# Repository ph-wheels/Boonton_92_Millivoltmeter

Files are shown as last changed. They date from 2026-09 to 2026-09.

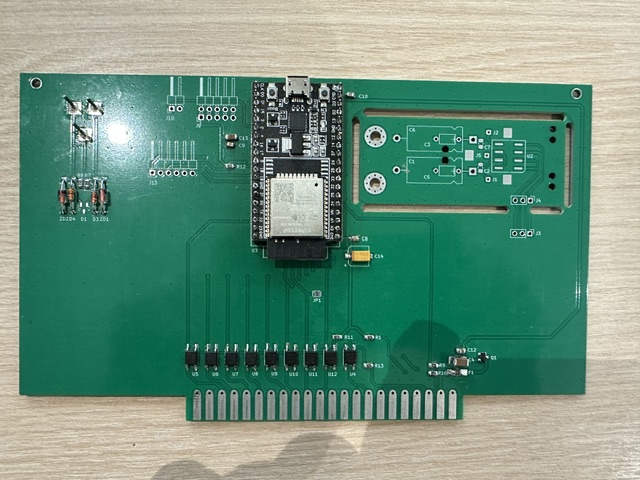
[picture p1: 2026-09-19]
IMG_92BD_V27.JPG

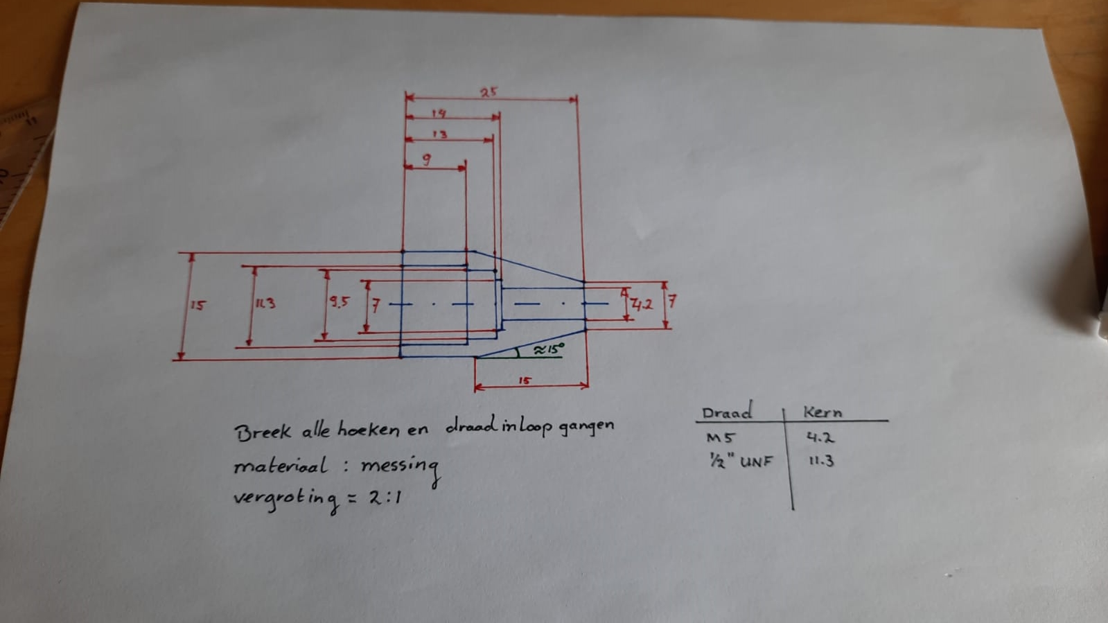
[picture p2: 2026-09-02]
IMG_92BD_Probe_Head.jpg

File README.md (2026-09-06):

# How to Fix & Add an Auto-Range Option to Your Boonton 92 Series RF Millivolt Meter

## Background

Some years ago I came across a 92BD RF Millivolt Meter in reasonably good condition. After a while it started showing problems that indicated the chopper tube was nearing end of life. Since these tubes are no longer available, the meter was effectively unusable.

I found a possible solution: replace the entire front end with a couple of low-drift op-amps and their associated gain-selection circuitry. This design was created by Jacques Audet, built on perfboard with a connector suitable for the 92 series backplane. I started laying out a PCB for it, but never actually built one.

## The SSR Idea

As part of another project, I became interested in solid-state relays (SSRs) that use MOSFETs, with the drive circuit electrically isolated from the signal. These devices can be driven with just a few mA, the MOSFET turns on within a microsecond, and it has very low Rds(on) resistance.

That's when the idea came up: replace the chopper tube with two SSRs (both housed in a single physical package). My original MCU-based auto-ranging extension board was redesigned into a new PCB that would handle both:

- The (already working) auto-ranging function, inital version ran on Arduino PCB
- The drive circuit for the SSRs

## Signal Path & Wiring

Since signal levels are quite low, and noise had to be minimized, I built an additional small PCB that mounts directly behind the signal input connector, with short leads to the SSR PCB and a single lead to the original analog input on the backplane.

A set of twisted control wires runs from the SSR PCB to a few free pins on backplane connector **J103**, which was originally intended for the auto-ranging board. On this connector, one additional connection is also needed: a jumper wire supplying +5V DC to the auto-ranging connector J103.

## System Overview

The current design consists of two parts, both controlled by the MCU:

1. **Auto-ranging circuit**
2. **SSR control circuit**

For the MCU I used an **ESP32** (with both Bluetooth and WiFi disabled). The choice was based on prior projects and the large number of available I/O pins.

### Handling Negative Control Voltages

The 92 series meter uses negative control voltages (up to −15V DC), while the MCU's pins are only 3.3V-tolerant. To bridge this gap, the design uses **9 optocouplers**:

- 8 for range selection
- 1 for auto-range mode

The analog voltage only needs to be measured after being reduced to below 3V, which is done with a small resistor divider network.

### Chopper Timing Emulation

The chopper section uses the original chopper tube connector, plugged directly into the PCB. Its voltage level is reduced to below 3.3V DC before being fed to the MCU as an input.

The MCU adjusts the signal output to the SSRs to match a contact timing similar to that of the original chopper tube, ensuring a proper **break-before-make** SPDT contact behavior is maintained.

Driving the opto input side of the SSR is simple — it only requires a single resistor to limit the LED current in the optocoupler.

## PCB Revision Notes

**V2.2 PCB** — Works well, but required some tweaks:

- Adjusted physical size
- Repositioned connectors
- Changed some GPIO port assignments
- Added a JTAG port
- Removed the serial port
- Added a few resistors

> **Note:** The small PCB embedded within the larger board needs to be separated and used behind the instrument's input connector, mounted on two short standoffs using the existing holes from the chopper tube bracket.



Build Notes & Firmware Update

This picture is from the V2.2 PCB — V2.7 has yet to be built and should give a much cleaner result. A few additional pictures (in the main folder) provide more detail on the build and required modifications.

The small SSR PCB only holds the original capacitors that came from the chopper tube socket. Note that the black stripe must be connected to the ground pads of C1 and C3. The SSR is then connected via short coax cables to the input connector and to the main analog PCB.

The SSR PCB was cut down primarily to reduce PCB fabrication cost — the main PCB has so much unused real estate that separating it out was the obvious choice.

## Calibration

Calibration of instrument it's self after de SSR mod can be done with the Boonton instrument calibration guidelines, once this is completed and no abnormal behaviour was found it's time to adjust the values for al and ah used by the auto range circuit.

This can easily be done by selecting the 1000mV range, apply a input signal of 1030 mV and read the ADC value with the 'a' command of the menu, the amount displayed will be your ah value.

Then repeat the same procedure but apply a input signal of 413 mV and read the ADC with the 'a' command of the menu, the amount displayed will be your al value.

These value should be validate with a DVM at the back side terminals, if they are off more than a few mV than your calibration if probably off.

Next type 'al xxx' <cr> (where xxx is the value obtained in the last step) and 'ah yyy' <cr> (where yyy is the value obtained in the first step)

Than check if they have been entered correctly by typing 'a' <cr>, that's all !!

## Latest firmware experiances

Firmware Redesign (Aug 30, 2026)

A completely redesigned firmware is now available. Early tests look promising, showing:

Improved signal stability
Cleaner code
Solid task isolation between auto-range, SSR driver, and the menu system with parameter storage

This was made possible largely thanks to Espressif's ESP32 FreeRTOS implementation (with help of Claude) — a real game-changer for the codebase.

Have fun building!

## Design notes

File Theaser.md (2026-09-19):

## will we ever get a V3 PCB ? (No)

Had fun making a lot of overdue changes in V2.7 and as a result I may create a V3 PCB with very small tweaks to the firmware

However my main reason was getting ride of the USB micro connector and migrate to a more modern version of the classic ESP32 vroom, on the other hand it doesn't make much sense

ESP32 vroom is going to be around for some time and conversion boards with more modern MCU to the current layout may become available in due time

Next main issue with the ESP32-C3 dev board is that it's lacking i/o pins so an extra 3-8 decoder will be needed

another reason is that one can buy on Ali-Express a ESP32 vroom with the USB-C connector and this solves all my current issue

So PCB V2.7 will be final one with it's gerbers and may get updated as needed, so far I have not seen any issue's with this PCB.

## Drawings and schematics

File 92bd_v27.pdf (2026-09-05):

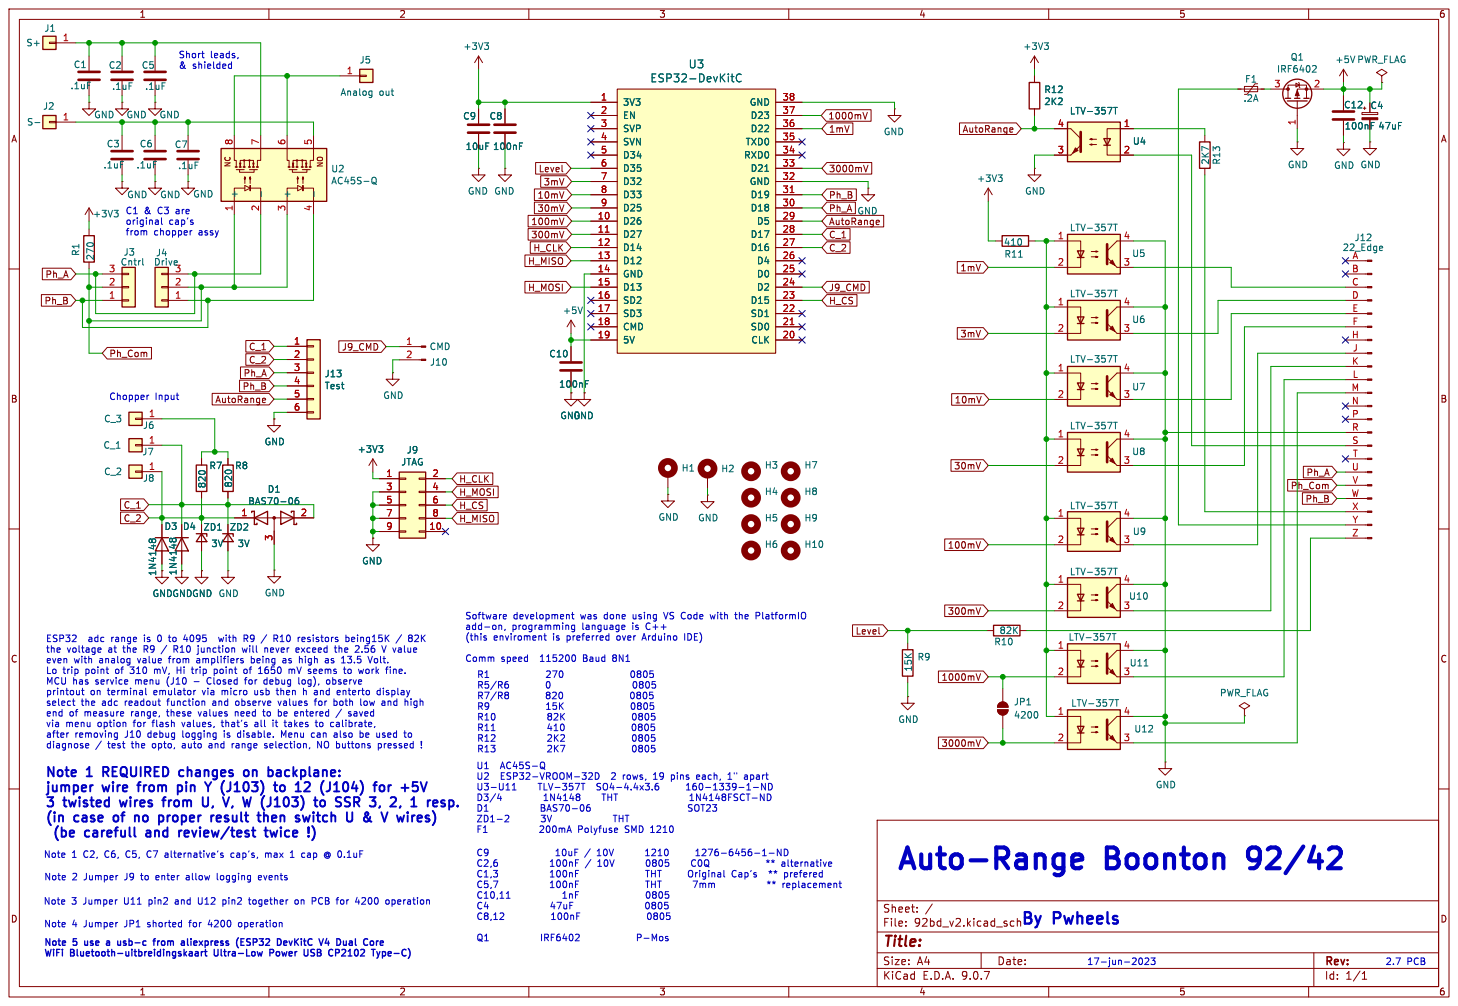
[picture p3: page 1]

end of measure range, these values need to be entered / saved

(in case of no proper result then switch U & V wires)

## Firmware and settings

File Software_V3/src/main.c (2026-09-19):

/*
* Boonton 92BD V3 firmware
* 
* This firmware is designed for the Boonton 92BD device to replace the original mechanical chopper
8 with a modern solid-state implementation as a input-follower logic with interlock, 
* ADC monitoring, and a serial menu interface for configuration & diagnostic
* this code is based on the ESP-IDF framework and uses FreeRTOS for task management.
* majority of this code is based extensive support of Claude AI field tested by meself.
* on my personally owned equipment and as a result of reverse enginering mechanical chopper
* and creating a modern replacement for it using the ESP32 platform.
* this to prevent an excellent piece of test equipment from being scrapped 
* due to the unavailability of the original mechanical chopper.
* current FW 3.0.7 replaces 1.6b1 and is based on HW PCB 2.7
*/
#include <stdio.h>
#include <string.h>
#include "freertos/FreeRTOS.h"
#include "freertos/task.h"
#include "driver/gpio.h"
#include "driver/uart.h"
#include "esp_timer.h"
#include "esp_task_wdt.h"
#include "esp_rom_sys.h"
#include "esp_log.h"
#include "nvs_flash.h"
#include "nvs.h"
#include "esp_adc/adc_oneshot.h"
#include "esp_adc/adc_cali.h"
#include "esp_adc/adc_cali_scheme.h"

//#define PCB_REV_2_2       1

/* ================= Pin configuration ================= */
#define OUT_PIN_Ph_A      GPIO_NUM_19   // phase A output may need to be swapped with phase B for syncronous chopper operation
#define OUT_PIN_Ph_B      GPIO_NUM_18   // phase B output may need to be swapped with phase A for syncronous chopper operation
#define OUT_PIN_1mV       GPIO_NUM_22
#define OUT_PIN_3mV       GPIO_NUM_32
#define OUT_PIN_10mV      GPIO_NUM_33
#define OUT_PIN_30mV      GPIO_NUM_25
#define OUT_PIN_100mV     GPIO_NUM_26
#define OUT_PIN_300mV     GPIO_NUM_27
#ifdef PCB_REV_2_2
  #define OUT_PIN_1000mV    GPIO_NUM_14  // <== true for Rev2.2 PCB, rev 2.7 requires GPIO_NUM_23
#else
  #define OUT_PIN_1000mV    GPIO_NUM_23  // <== true for Rev2.2 PCB, rev 2.7 requires GPIO_NUM_23
#endif
#define OUT_PIN_3000mV    GPIO_NUM_21

#define IN_PIN_C_2        GPIO_NUM_16   // inputs from the 92BD's internal chooper connector
#define IN_PIN_C_1        GPIO_NUM_17   // inputs from the 92BD's internal chooper connector
#define IN_PIN_Auto       GPIO_NUM_5    // enable auto ranging system
//#define IN_PIN_Opt        GPIO_NUM_2    /// optional input for future use, not currently used

#define OUTPUT_ACTIVE_LOW  1   // outputs: ON = pin driven low
#define INPUT_ACTIVE_LOW   1   // inputs:  active = pin read low

#define ADC_level         GPIO_NUM_35   // feedback ADC input from the 92BD's internal analog source, used for auto-ranging decisions
#define ADC_UNIT          ADC_UNIT_1
#define ADC_CHANNEL       ADC_CHANNEL_7   // GPIO35 on ESP32 = ADC1_CH7
#define ADC_ATTEN         ADC_ATTEN_DB_12 // ~0-3.1V full scale at the pin (post-divider)
#define ADC_BITWIDTH      ADC_BITWIDTH_DEFAULT
#define ADC_SAMPLE_COUNT  8               // averaging
#define ADC_TASK_PERIOD_MS 100

/* ================= Timing configuration ================= */

#define SCAN_PERIOD_US       10600U   // 94 Hz +/- 1% scan/chopper rate
#define DEAD_TIME_DEFAULT_US 120U     // was 1060U -- capped at 500us max per requirement
#define DEAD_TIME_MIN_US     40U
#define DEAD_TIME_MAX_US     200U     // was 200U -- hard ceiling now matches the default cap

#define VERSION "3.0.7"      // 3.0.0 initial freeRTOS implementation
                             // 3.0.1 adjusted selectable range of various parameter for NVS
                             // 3.0.2cleanup of menu wording / layot
                             // 3.0.3 dropped usage of input CMD & M42
                             // 3.0.4 added log gate functionality
                             // 3.0.5 conditional usage of GPIO_NUM_14 
                             //       or GPIO_NUM_23 for OUT_PIN_1000mV based on PCB_REV_2_2 define
                             // 3.0.6 added range_hyst_mv to menu and NVS, added range_settle_ms to menu and NVS,
                             // 3.0.7 added l y/n option, default & power-on logging off

#define NVS_KEY_DEADTIME     "dead_time_us"
#define NVS_KEY_ADC_LOW      "adc_low_mv"
#define NVS_KEY_ADC_HIGH     "adc_high_mv"
#define NVS_KEY_RANGE_SETTLE "range_settle_ms"

#define ADC_LOW_MIN_MV       300
#define ADC_LOW_MAX_MV       600
#define ADC_HIGH_MIN_MV      1000
#define ADC_HIGH_MAX_MV      2000

#define RANGE_SETTLE_MIN_MS  10
#define RANGE_SETTLE_MAX_MS  500

#define UART_PORT_NUM    UART_NUM_0
#define UART_BUF_SIZE    256

#define NVS_NAMESPACE     "settings"
#define NVS_KEY_DEADTIME  "dead_time_us"

#define RANGE_COUNT              8
#define RANGE_SWITCH_DEAD_US     100    // break-before-make gap between range pins

#define NVS_KEY_RANGE_HYST   "range_hyst_mv"
#define RANGE_HYST_MIN_MV    0
#define RANGE_HYST_MAX_MV    500


static const gpio_num_t s_range_pins[RANGE_COUNT] = {
    OUT_PIN_1mV, OUT_PIN_3mV, OUT_PIN_10mV, OUT_PIN_30mV,
    OUT_PIN_100mV, OUT_PIN_300mV, OUT_PIN_1000mV, OUT_PIN_3000mV
};

static int64_t s_last_range_switch_us = 0;

static const char *TAG = "92BD";

/* ================= Shared runtime-adjustable state ================= */
static volatile uint32_t s_dead_time_us   = DEAD_TIME_DEFAULT_US;
static volatile int32_t  s_adc_low_mv     = 400;    // range floor, mV
static volatile int32_t  s_adc_high_mv    = 1700;   // range ceiling, mV
static volatile int32_t  s_adc_last_mv    = 0;      // last calibrated reading
static volatile int8_t   s_adc_range_stat = 0;      // -1 / 0 / +1
static volatile bool     s_input_fault    = false;  // both inputs active simultaneously
static volatile int32_t  s_range_hyst_mv  = 50;     // extra margin beyond al/ah before switching, mV
static volatile uint32_t s_range_settle_ms = 150;   // default, overridden by NVS if present
static bool s_auto_was_active = false;              // tracks Auto's previous state, for edge detection
static volatile uint8_t s_adc_range_index = 0;
static bool s_log_enabled = false;                  // logging off by default at every boot, no NVS

static TaskHandle_t s_io_task_handle = NULL;

#include "freertos/queue.h"

typedef struct {
    gpio_num_t pin;
    bool active;      // true = just went active (falling edge on active-low input)
    bool heartbeat;   // true = this is just a WDT heartbeat tick, ignore pin/active
} phase_event_t;

static QueueHandle_t s_phase_evt_queue;

/* ================= Output / input helpers ================= */
static inline void output_set(gpio_num_t pin, bool on)
{
#if OUTPUT_ACTIVE_LOW
    gpio_set_level(pin, on ? 0 : 1);
#else
    gpio_set_level(pin, on ? 1 : 0);
#endif
}

static inline bool input_is_active(gpio_num_t pin)
{
    int level = gpio_get_level(pin);
#if INPUT_ACTIVE_LOW
    return level == 0;
#else
    return level == 1;
#endif
}

/* ================= Range switching helpers ================= */
static void range_apply(uint8_t new_idx)
{
    if (new_idx >= RANGE_COUNT) return;
    if (new_idx == s_adc_range_index) return;

    output_set(s_range_pins[s_adc_range_index], false);  // old range off
    esp_rom_delay_us(RANGE_SWITCH_DEAD_US);               // guaranteed gap
    output_set(s_range_pins[new_idx], true);              // new range on

    s_adc_range_index = new_idx;
    s_last_range_switch_us = esp_timer_get_time();
    ESP_LOGI(TAG, "Auto-range switched to index %u (%s)", new_idx,
             new_idx == 0 ? "1mV" : new_idx == 7 ? "3000mV" : "intermediate");
}

static void range_all_off(void)
{
    for (int i = 0; i < RANGE_COUNT; i++) {
        output_set(s_range_pins[i], false);
    }
}

/* Called exactly once, on the transition into Auto-active */
static void range_enter(uint8_t start_idx)
{
    range_all_off();                        // guarantee known state regardless of history
    esp_rom_delay_us(RANGE_SWITCH_DEAD_US);  // break-before-make even from the "all off" state
    output_set(s_range_pins[start_idx], true);
    s_adc_range_index = start_idx;
    s_last_range_switch_us = esp_timer_get_time();
    ESP_LOGI(TAG, "Auto-ranging engaged, starting at range index %u", start_idx);
}

/* Called exactly once, on the transition out of Auto-active */
static void range_exit(void)
{
    range_all_off();
    ESP_LOGI(TAG, "Auto-ranging disengaged, all ranges off");
}

static void auto_range_update(int8_t status)
{
    bool active = input_is_active(IN_PIN_Auto);

    if (active && !s_auto_was_active) {
        range_enter(0);
        s_auto_was_active = true;
        return;
    }
    if (!active && s_auto_was_active) {
        range_exit();
        s_auto_was_active = false;
        return;
    }
    if (!active) return;

    int64_t now = esp_timer_get_time();
    if (now - s_last_range_switch_us < ((int64_t)s_range_settle_ms * 1000)) return;

    int32_t mv = s_adc_last_mv;                 // use the raw reading directly, not just the -1/0/+1 status
    int32_t hyst = s_range_hyst_mv;

    if (mv > (s_adc_high_mv + hyst) && s_adc_range_index < RANGE_COUNT - 1) {
        range_apply(s_adc_range_index + 1);
    } else if (mv < (s_adc_low_mv - hyst) && s_adc_range_index > 0) {
        range_apply(s_adc_range_index - 1);
    }
}

/* ================= NVS: generic int32 load/save ================= */
static bool nvs_load_i32(const char *key, int32_t min, int32_t max, int32_t *out_val)
{
    nvs_handle_t h;
    bool ok = false;
    if (nvs_open(NVS_NAMESPACE, NVS_READONLY, &h) == ESP_OK) {
        int32_t val = 0;
        if (nvs_get_i32(h, key, &val) == ESP_OK && val >= min && val <= max) {
            *out_val = val;
            ok = true;
            ESP_LOGI(TAG, "Loaded %s=%ld from NVS", key, (long)val);
        }
        nvs_close(h);
    }
    return ok;
}

static bool nvs_save_i32(const char *key, int32_t val)
{
    nvs_handle_t h;
    if (nvs_open(NVS_NAMESPACE, NVS_READWRITE, &h) != ESP_OK) return false;
    esp_err_t err = nvs_set_i32(h, key, val);
    if (err == ESP_OK) err = nvs_commit(h);
    nvs_close(h);
    if (err != ESP_OK) {
        ESP_LOGE(TAG, "NVS save failed for %s: %s", key, esp_err_to_name(err));
    }
    return err == ESP_OK;
}

/* ================= Periodic scan tick (esp_timer -> notify) ================= */
static void IRAM_ATTR c_input_isr_handler(void *arg)
{
    gpio_num_t pin = (gpio_num_t)(uint32_t)arg;
    int level = gpio_get_level(pin);
    bool active = INPUT_ACTIVE_LOW ? (level == 0) : (level == 1);
    phase_event_t evt = { .pin = pin, .active = active, .heartbeat = false };
    BaseType_t woken = pdFALSE;
    xQueueSendFromISR(s_phase_evt_queue, &evt, &woken);
    if (woken) portYIELD_FROM_ISR();
}

static void IRAM_ATTR heartbeat_timer_cb(void *arg)
{
    phase_event_t evt = { .heartbeat = true };
    BaseType_t woken = pdFALSE;
    xQueueSendFromISR(s_phase_evt_queue, &evt, &woken);
    if (woken) portYIELD_FROM_ISR();
}

/* ================= Task 1 (highest priority): input-follower with interlock ================= */
typedef enum { OUT_NONE = 0, OUT_ACTIVE_1, OUT_ACTIVE_2 } out_state_t;

static void io_task(void *pvParameters)
{
    ESP_ERROR_CHECK(esp_task_wdt_add(NULL));

    s_phase_evt_queue = xQueueCreate(16, sizeof(phase_event_t));
    configASSERT(s_phase_evt_queue != NULL);

    // Heartbeat: guarantees a periodic WDT feed independent of whether
    // C_1/C_2 are actually toggling (see note above if you'd prefer otherwise).
    const esp_timer_create_args_t hb_args = { .callback = &heartbeat_timer_cb, .name = "hb_timer" };
    esp_timer_handle_t hb_timer;
    ESP_ERROR_CHECK(esp_timer_create(&hb_args, &hb_timer));
    ESP_ERROR_CHECK(esp_timer_start_periodic(hb_timer, SCAN_PERIOD_US)); // 10.6ms

    output_set(OUT_PIN_Ph_A, false);
    output_set(OUT_PIN_Ph_B, false);

    static bool c1_active = false, c2_active = false;
    phase_event_t evt;

    for (;;) {
        if (xQueueReceive(s_phase_evt_queue, &evt, pdMS_TO_TICKS(50)) == pdTRUE && !evt.heartbeat) {
            uint32_t dead_us = s_dead_time_us; // snapshot, runtime-adjustable

            if (evt.pin == IN_PIN_C_1) {
                c1_active = evt.active;
                if (evt.active) {
                    output_set(OUT_PIN_Ph_B, false);   // force-off the other side first
                    esp_rom_delay_us(dead_us);         // guaranteed gap before energizing
                    output_set(OUT_PIN_Ph_A, true);
                } else {
                    output_set(OUT_PIN_Ph_A, false);   // deactivate immediately, no delay
                }
            } else if (evt.pin == IN_PIN_C_2) {
                c2_active = evt.active;
                if (evt.active) {
                    output_set(OUT_PIN_Ph_A, false);
                    esp_rom_delay_us(dead_us);
                    output_set(OUT_PIN_Ph_B, true);
                } else {
                    output_set(OUT_PIN_Ph_B, false);
                }
            }

            s_input_fault = c1_active && c2_active; // both active simultaneously = fault flag
        }

        // Runs every loop pass (real event, heartbeat, or 50ms timeout fallback) -
        // WDT is fed at least every ~10.6ms in normal operation.
        esp_task_wdt_reset();
    }
}

/* ================= ADC calibration + classification ================= */
static adc_oneshot_unit_handle_t s_adc_handle;
static adc_cali_handle_t s_adc_cali_handle = NULL;
static bool s_adc_cali_ok = false;

static bool adc_calibration_init(adc_unit_t unit, adc_channel_t channel, adc_atten_t atten,
                                  adc_cali_handle_t *out_handle)
{
    adc_cali_handle_t handle = NULL;
    esp_err_t ret = ESP_FAIL;

#if ADC_CALI_SCHEME_CURVE_FITTING_SUPPORTED
    adc_cali_curve_fitting_config_t cfg = {
        .unit_id = unit, .chan = channel, .atten = atten, .bitwidth = ADC_BITWIDTH,
    };
    ret = adc_cali_create_scheme_curve_fitting(&cfg, &handle);
#elif ADC_CALI_SCHEME_LINE_FITTING_SUPPORTED
    adc_cali_line_fitting_config_t cfg = {
        .unit_id = unit, .atten = atten, .bitwidth = ADC_BITWIDTH,
#if CONFIG_IDF_TARGET_ESP32
        .default_vref = 1100,   // fallback mV used only if no eFuse Vref/TP calibration is burned
#endif
    };
    ret = adc_cali_create_scheme_line_fitting(&cfg, &handle);
#endif
    *out_handle = handle;
    if (ret == ESP_OK) {
        ESP_LOGI(TAG, "ADC calibration scheme created OK (using %s)",
                 ret == ESP_OK ? "eFuse or default_vref fallback" : "n/a");
    }
    return ret == ESP_OK;
}

/* Returns -1 below range, 0 within range, +1 above range */
static int8_t adc_classify(int32_t mv)
{
    if (mv < s_adc_low_mv)  return -1;
    if (mv > s_adc_high_mv) return  1;
    return 0;
}

/* ================= Task: ADC monitor ================= */
static void adc_task(void *pvParameters)
{
    ESP_ERROR_CHECK(esp_task_wdt_add(NULL));

    adc_oneshot_unit_init_cfg_t init_cfg = { .unit_id = ADC_UNIT };
    ESP_ERROR_CHECK(adc_oneshot_new_unit(&init_cfg, &s_adc_handle));

    adc_oneshot_chan_cfg_t chan_cfg = { .atten = ADC_ATTEN, .bitwidth = ADC_BITWIDTH };
    ESP_ERROR_CHECK(adc_oneshot_config_channel(s_adc_handle, ADC_CHANNEL, &chan_cfg));

    s_adc_cali_ok = adc_calibration_init(ADC_UNIT, ADC_CHANNEL, ADC_ATTEN, &s_adc_cali_handle);
    if (!s_adc_cali_ok) {
        ESP_LOGW(TAG, "ADC calibration not available on this chip/eFuse - readings will be raw-only");
    }

    for (;;) {
        int32_t sum_raw = 0;
        for (int i = 0; i < ADC_SAMPLE_COUNT; i++) {
            int raw = 0;
            adc_oneshot_read(s_adc_handle, ADC_CHANNEL, &raw);
            sum_raw += raw;
            esp_rom_delay_us(50); // small gap between samples
        }
        int raw_avg = sum_raw / ADC_SAMPLE_COUNT;

        int mv = 0;
        if (s_adc_cali_ok) {
            adc_cali_raw_to_voltage(s_adc_cali_handle, raw_avg, &mv);
        } else {
            mv = raw_avg; // fallback: unscaled, treat thresholds as raw counts in this case
        }

        s_adc_last_mv    = mv;
        s_adc_range_stat = adc_classify(mv);

        auto_range_update(s_adc_range_stat);   // auto-range switching if enabled and needed

        esp_task_wdt_reset();
        vTaskDelay(pdMS_TO_TICKS(ADC_TASK_PERIOD_MS));
    }
}

/* ================= Task: serial menu ================= */
static void print_menu(void)
{
    printf("\r\n--- Menu --- Boonton %s --- Version %s\r\n", TAG, VERSION);
    printf("s                Show status\r\n");
    printf("d                Show dead_time_us\r\n");
    printf("d  <us>  (120)   Set dead_time_us (%u-%u), saved to NVS\r\n", DEAD_TIME_MIN_US, DEAD_TIME_MAX_US);
    printf("al <mv>  (490)   Set ADC low threshold (mV), saved to NVS\r\n");
    printf("ah <mv>  (1600)  Set ADC high threshold (mV), saved to NVS\r\n");
    printf("a                Show ADC reading + range status\r\n");
    printf("rs               Show range_settle_ms\r\n");
    printf("rs <ms>  (150)   Set range_settle_ms (%u-%u), saved to NVS\r\n", RANGE_SETTLE_MIN_MS, RANGE_SETTLE_MAX_MS);
    printf("rh <mv>  (10)    Set range hysteresis (mV), saved to NVS\r\n");
    printf("rng <0-7>        Manually force range index (bypasses Auto)\r\n");
    printf("l  y/n           Enable/disable ESP_LOG output (default: off, not saved)\r\n");
    printf("                 Advised  value's in (), changing dead_time requires calibration !\r\n> ");
    printf("h                Help.\r\n> ");
    fflush(stdout);
}
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
void app_main(void)
{
    esp_err_t err = nvs_flash_init();
    if (err == ESP_ERR_NVS_NO_FREE_PAGES || err == ESP_ERR_NVS_NEW_VERSION_FOUND) {
        ESP_ERROR_CHECK(nvs_flash_erase());
        err = nvs_flash_init();
    }
    ESP_ERROR_CHECK(err);
    
     int32_t val;
    if (nvs_load_i32(NVS_KEY_DEADTIME, DEAD_TIME_MIN_US, DEAD_TIME_MAX_US, &val)) {
        s_dead_time_us = (uint32_t)val;
    }
    if (nvs_load_i32(NVS_KEY_ADC_LOW, ADC_LOW_MIN_MV, ADC_LOW_MAX_MV, &val)) {
        s_adc_low_mv = val;
    }
    if (nvs_load_i32(NVS_KEY_ADC_HIGH, ADC_HIGH_MIN_MV, ADC_HIGH_MAX_MV, &val)) {
        s_adc_high_mv = val;
    }
    if (nvs_load_i32(NVS_KEY_RANGE_SETTLE, RANGE_SETTLE_MIN_MS, RANGE_SETTLE_MAX_MS, &val)) {
        s_range_settle_ms = (uint32_t)val;
    }
    if (nvs_load_i32(NVS_KEY_RANGE_HYST, RANGE_HYST_MIN_MV, RANGE_HYST_MAX_MV, &val)) {
        s_range_hyst_mv = val;
    }

    // Outputs
    gpio_config_t out_conf = {
        .pin_bit_mask = (1ULL << OUT_PIN_Ph_A) | (1ULL << OUT_PIN_Ph_B) | \
        (1ULL << OUT_PIN_1mV) | (1ULL << OUT_PIN_3mV) | (1ULL << OUT_PIN_10mV) | \
        (1ULL << OUT_PIN_30mV) | (1ULL << OUT_PIN_100mV) | (1ULL << OUT_PIN_300mV) | \
        (1ULL << OUT_PIN_1000mV) | (1ULL << OUT_PIN_3000mV),
        .mode = GPIO_MODE_OUTPUT,
    };
    gpio_config(&out_conf);
    output_set(OUT_PIN_Ph_A, false);
    output_set(OUT_PIN_Ph_B, false);
    output_set(OUT_PIN_1mV, false);
    output_set(OUT_PIN_3mV, false);
    output_set(OUT_PIN_10mV, false);
    output_set(OUT_PIN_30mV, false);
    output_set(OUT_PIN_100mV, false);
    output_set(OUT_PIN_300mV, false);
    output_set(OUT_PIN_1000mV, false);
    output_set(OUT_PIN_3000mV, false);

    /* ========= make sure all range outputs are disabled ========= */
    for (int i = 0; i < RANGE_COUNT; i++) {
        output_set(s_range_pins[i], false);
    }
    s_adc_range_index = 0;        // not meaningful until Auto engages
    s_last_range_switch_us = 0;

    // Inputs (active-low -> internal pull-up)
    gpio_config_t in_conf = {
        .pin_bit_mask = (1ULL << IN_PIN_C_2) | (1ULL << IN_PIN_C_1) | (1ULL << IN_PIN_Auto),
        .mode = GPIO_MODE_INPUT,
    #if INPUT_ACTIVE_LOW
        .pull_up_en = GPIO_PULLUP_ENABLE,
        .pull_down_en = GPIO_PULLDOWN_DISABLE,
    #else
        .pull_up_en = GPIO_PULLUP_DISABLE,
        .pull_down_en = GPIO_PULLDOWN_ENABLE,
    #endif
        .intr_type = GPIO_INTR_DISABLE,   // default; C_1/C_2 overridden below
    };
    gpio_config(&in_conf);

    // Edge-triggered interrupts specifically for the two phase inputs
    ESP_ERROR_CHECK(gpio_set_intr_type(IN_PIN_C_1, GPIO_INTR_ANYEDGE));
    ESP_ERROR_CHECK(gpio_set_intr_type(IN_PIN_C_2, GPIO_INTR_ANYEDGE));
    ESP_ERROR_CHECK(gpio_install_isr_service(0));
    ESP_ERROR_CHECK(gpio_isr_handler_add(IN_PIN_C_1, c_input_isr_handler, (void *)IN_PIN_C_1));
    ESP_ERROR_CHECK(gpio_isr_handler_add(IN_PIN_C_2, c_input_isr_handler, (void *)IN_PIN_C_2));

    // UART for menu
    uart_config_t uart_config = {
        .baud_rate = 115200,
        .data_bits = UART_DATA_8_BITS,
        .parity    = UART_PARITY_DISABLE,
        .stop_bits = UART_STOP_BITS_1,
        .flow_ctrl = UART_HW_FLOWCTRL_DISABLE,
    };
    uart_param_config(UART_PORT_NUM, &uart_config);
    uart_driver_install(UART_PORT_NUM, UART_BUF_SIZE * 2, 0, 0, NULL, 0);

    esp_log_level_set("*", ESP_LOG_NONE);   // silent until explicitly enabled via menu

    // Task watchdog
    esp_task_wdt_config_t twdt_config = {
        .timeout_ms = 1000,
        .idle_core_mask = 0,
        .trigger_panic = true,
    };
    esp_task_wdt_reconfigure(&twdt_config);

    xTaskCreatePinnedToCore(io_task, "io_task", 4096, NULL,
                             configMAX_PRIORITIES - 1, &s_io_task_handle, 1);
    xTaskCreatePinnedToCore(adc_task, "adc_task", 4096, NULL, 4, NULL, 1);
    xTaskCreatePinnedToCore(menu_task, "menu_task", 4096, NULL, 5, NULL, 0);
}

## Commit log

2026-09-01 Add files via upload
    This software is to replace all previous version as to assure improved measurement stability
    [main.c]
2026-09-01 Add files via upload
    this is a direct replacement for an previous version, providing far better stability
    [main.c]
2026-09-01 Add files via upload
    image for current version provide for easy start
2026-09-01 Modify OUT_PIN_1000mV for PCB revision updates
    Updated OUT_PIN_1000mV definition to reflect PCB revision changes.
2026-09-01 Add firmware note for REV 2.7 PCB
    Add note about firmware compatibility with REV 2.7 PCB.
2026-09-01 Add conditional definition for OUT_PIN_1000mV
    adjustment for pin change between pcb version
2026-09-02 Add files via upload
    drawing to create a rf probe tip
2026-09-03 Add files via upload
    New gerber file, fixed some issue's
    [92bd_v2-B_Cu.gbr]
2026-09-03 Add files via upload
    new gerber files, applied changes and fixed some issue
2026-09-03 Revise README for clarity and structure
    Updated the README to improve clarity and fix grammar issues. Added sections for background, SSR idea, signal path, system overview, and PCB revision notes.
2026-09-03 Add update on overdue changes and potential V3 PCB
2026-09-05 Add calibration instructions for SSR modified instrument
    Added calibration instructions for the instrument after SSR modification, detailing the steps to adjust 'al' and 'ah' values using specific input signals.
2026-09-05 Add calibration instructions for SSR mod
    Added a section on calibration after SSR modification, detailing the adjustment process for al and ah values.
2026-09-05 Revise Theaser.md for V3 PCB discussion
    Updated Theaser.md to reflect changes regarding V3 PCB and ESP32.
2026-09-06 Add files via upload
    fixed some naming & grounding
2026-09-06 Update firmware version and ADC settings
    Updated firmware version to 3.0.7 and adjusted ADC thresholds. Removed log gate update function and modified logging behavior.
2026-09-06 Update README with calibration validation and credit
    Added validation step for calibration values and credited Claude for help with FreeRTOS implementation.
2026-09-06 Update README to include Arduino PCB details
    Added clarification about the initial version running on Arduino PCB.
2026-09-19 Add files via upload
    It's finally avaible & tested V27 PCB
2026-09-19 Add files via upload
    V2.7 PCB rotated view
2026-09-19 Comment out PCB_REV_2_2 definition
    Comment out the PCB_REV_2_2 definition for flexibility.
    as V2.7 PCB are available that now default of pins used
